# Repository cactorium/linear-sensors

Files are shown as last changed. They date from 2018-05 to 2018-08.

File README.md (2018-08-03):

# Linear PCB sensors
This will eventually contain the sensing mechanisms for several different types of digital calipers.
Luckily the patents on all of them have run out, so I can copy a lot of the exact details used in existing calipers, which should mean there's a lot of a better chance of getting good results out of this.
The designs will be made in KiCAD, and will be under a sufficiently liberal license for you guys to use for whatever.
Hopefully these will be cheap and easy enough to use for a lot of interesting applications, like close looping the axes on 3D printers for a lot cheaper than the $1k+ optical scales that's used on higher end models right now.

**NOTE: the schematic and PCB are now in KiCAD 5. I don't know how backwards compatible it is with older version of KiCAD**

## Capacitance-based sensor v1
~The capactive sensor appears to be working right now, with a sample rate of 96 samples/sec and a precision of about ~ +-0.06 mm (~ +-0.002in), limited by noise.
The accuracy appears to stay within +- 0.01mm for a lot of the range, but the inaccuracy increases at various points (and also if you're touching the scale) along its range.
It's currently affected moderately strongly by mains noise, the next revision will add better filtering to the front end to reduce this issue.~
So the signal is actually incredibly accurate, as long as the surfaces are closely mating and the amplifier isn't clipping.
I'm getting about ~0.002 mm precision (still need to check accuracy across the full range) after carefully adjusting gain to remove clipping.
The signal doesn't appear anything near a sine wave at the output, it mainly consists of a lot of sharp spikes that I guess the FIRs turn into something closer to a sine wave.
It's currently probably limited by the numerical accuracy of the arctangent operation in the processing, but I need to do more testing to see how accurate it is across its range before tuning its precision any more.

There also appear to be some large inaccuracies across its full range, which also I'm currently working out.

## Capacitance-based sensor v2
I reduced the width of the scale by half to try to improve the form factor and added a second stage of filtering to try to reduce its susceptibility to noise.
I removed the large metallic layer that used to overlap the receiving pad to see if that would reduce the amount of noise.
I'm pretty sure covering it with ground will reduce the output signal by adding a lot of parasitic capacitance, so right now it's bare aside from a trace to get the signal from the receiving pad.
There's now three stages of amplification, the first one, which is adjustable and has a gain from 1x to 10x, and two fixed stages which are 2x and ~10x respectively.
There's several stages of low pass and high pass filtering throughout all this, plus some bypass resistors in case this all turns out wrong so I can revert to the v1 analog circuitry in the worst case.
The edges of the PCB were also rounded just to make it look a little nicer, and the mounting holes are now evenly spaced to make mechanical stuff a lot easier to work out.

The BOM cost is about $16, which is pretty reasonable, but I'll probably try to get it a little lower next revision.

The extra filter does appear to work very nicely; the output actually looks like a sine wave, so it might be possible to remove some of the digital filtering while maintaining the same accuracy, but I'm going to work on mechanically stabilizing the setup to get more repeatable measurements.
It does appear to be noticeably better just from rough observations; it takes a lot less effort to get the measurement to where it's bouncing around +- 0.001mm compared with the first revision.
I'm guessing the next revision will focus on improving the form factor and cost.

TODO: add pictures

## How they work
Right now I'm looking at two major designs, inductively coupled ones, developed by Mitutoyo, and the T-shaped capacitively coupled ones used in most cheap caliper designs by Mauser-Werke Oberndorf GmbH.
In both cases, the basic gist is that there's a pattern on the stationary bit (called the stator) that affects its coupling with the bit that moves (let's call it the rotor), and in both cases a phase measurement based on measurements as a result of this coupling is used to get a fine measurement, while a counter is used to keep track of how many times the phase has gone about 360 degrees, giving a coarse measurement.
The actual measurement is simply the sum of these two measurements.

In the Mitutoyo design, a pulse is sent into a transmitting coil, which causes it to resonate.
The EM waves produced by this coil are coupled into a pair of receiving coils.
The receiving coils are shaped so that normally the EM waves perfectly cancel out, but the presence and displacement of the disruptors in the stator cause the cancellation to be incomplete.
The receiving coils are shaped so that they form a sine and cosine wave with respect to the displacement relative to the stator.
The receiving coils resonate in series with a capacitor, and a switch is used to stop the resonation near when the voltage across the capacitor is at its peak.
Then the voltage across the capacitors are read using an ADC, and that's used to calculate the displacement within a single stator period.
A counter's used to get the coarser measurement when the stator's moved greater than one period.

In the Mauser-Werke Oberndorf design, there's many transmitting electrodes, each at a different phase.
Each one is shifted by the same amount relative to the one before it.
In the original design, they formed a set of three before it repeated, with relative phases of 0, 120, 240 degrees.
Modern designs tend to use a set of 8, so that's what we'll use here.
These transmitting electrodes couple with the middle of the tee in the stator design, so that the signal read off the T electrode is effectively the capcitively weighted sum of the electrodes that are coupled (physically over) it.
Shifting the rotor causes the ratios to change, allowing an (very good) approximately linear change in phase for a given displacement.
The wider sections of the T are capactively coupled with a receiving electrode on the rotor, and this is filtered and fed into a zero crossing detector to determine the phase different compared with the input signal, giving you a fine measurement of displacement.
The coarse measurement is found by counting, as in the Mitutoyo case.

TODO add patents to repository

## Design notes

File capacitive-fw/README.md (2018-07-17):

# Firmware for the capacitive sensor board
This is probably not the cleanest directory structure ever, but it works.
The firmware developed here is meant to be programmed onto the STM32F07 chip on the capacitive board.
This provides UART output on the J102 header at 115200 baud (adjustable in the source code) of the current position, output as a 64 bit hexadecimal, followed by a space and 64 zeros (TODO remove extra output).
The button on the board zeros out the reading, and the reading can also be zeroed out by sending a "z" into the UART port.

The project is currently using `libopencm3` to avoid needing to read through the STM32F07 reference manual, and the OpenOCD config is for the FT232H chip. TODO provide more info about SWD programming with Adafruit's FT232H breakout
Any SWD-capable OpenOCD-compatible programmer should work.
You'll need the `arm-none-eabi-gcc` toolchain to build the project, although I'll probably add the final binaries to this repository at some point.

## How it works (TLDR)
Basically the position is approximately linear with respect to the detected phase of the signal, so the MCU needs to clean up the signal and find its phase to find its position.

## Internals
Most of the processing is done in the main loop, with interrupts providing the timing for the ADC conversion and square waves.
The system tick interrupt provides the timing for the entire system; it starts ADC conversions and toggles GPIO for the square waves.
The ADC interrupts stores the samples into a buffer, where it'll be slowly processed by the main loop.
Due to the limitations in processing speed, the ADC doesn't run continuously.
Instead, the ADC runs for the first N cycles of the square waves, enough to fill the buffer, with the ADC turned off for the remaining portion of the time. (maybe this is leading to more noise? TODO experiment with changing timing)
The number of ADC cycles and total cycles are easily adjusted to allow experimentation to try to improve latency or improve performance.
There's an overrun detector that'll output an 'o' onto the UART line whenever the main loop is taking too long to process the data.

The main loop passes the ADC samples into a cascade of three FIR filters, to reduce a lot of the mains noise and harmonics in the signal.
This is then multiplied with a 1 kHz cosine and 1 kHz sine wave to produce I (in phase) and Q (quadrature) components, which are summed over the entire sampling period.
This is then fed into an arctangent function based on CORDIC (Volder's algorithm) to produce this final phase information.

A lot of the experimenting done to design these filters and test out CORDIC is available under the `filter/` directory.

All of the math is done in a mixture of 32-bit and 64-bit math, with care to avoid any unnecessary multiplication and to avoid doing any divisions with anything other than a power of 2.
This proved vital in reaching the desired performance of the unit.

### Development notes
All the Python files in `src/` are used to generate constants and headers and stuff.
TODO add these to the Makefile

## How to build

```
cd src/
make
make flash
```

## TODOs
- [ ] Wire up the voltage protection MOSFET correctly
- [ ] Switch out JTAG header with SMD one
- [ ] Add front end filter components
- [ ] Maybe swap to a higher performance MCU
- [ ] Order and test on a longer scale board
- [ ] Test and verify that the board is actually outputting accurate data

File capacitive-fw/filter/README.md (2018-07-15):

Testing out the FIR filters to use on the STM32; there's a lot of 60 Hz noise and harmonics in the signal, so we need to filter them out before using the periodogram to calculate phase.

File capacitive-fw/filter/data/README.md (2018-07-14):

Data was collected using commit `cbe28079ba94519dbe33b98c67d5848d1041f939` version of the code.
In this version of the code, sending a 'd' across the USART causes the program to dump its 1000 samples of ADC data in hex.

So I ran this in one terminal:
```
cat /dev/ttyUSB0 > data0
```
and opened up picocom in another and pressed 'd'

There's probably a better way to do it but this works well enough

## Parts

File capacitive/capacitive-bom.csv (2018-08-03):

Reference | Quantity | Identifier | Package | Value | Tolerance | Voltage | Current | Power | PN | Mouser
U101 | 1 |  |  | STM32F070C6T6 |  |  |  |  |  | 511-STM32F070C6T6
C111;C103;C110;C101;C104;C105;C102;C118;C121;C112;C113;C107 | 12 |  |  | 100nF 20% |  |  |  |  |  | 710-885012207016
R103;R119 | 2 |  |  | 1.58k 1% |  |  |  |  |  | 660-RN73H1JTD1581D25
C108;C125 | 2 |  |  | 100nF 2% |  |  |  |  |  | 667-ECH-U1C104GX5
C109 | 1 |  |  | 10 nF 1% |  |  |  |  |  | 81-GRM2195C1H103FA1D
R105;R126;R102 | 3 |  |  | 1k 1% |  |  |  |  |  | 71-CRCW04021K00FKEDC
R108;R115;R124 | 3 |  |  | DNP |  |  |  |  |  | 71-RCS06030000Z0EA
J102 | 1 |  |  | UART |  |  |  |  |  | 855-M20-9990445
J103 | 1 |  |  | SWD |  |  |  |  |  | 855-M20-8750342
C106 | 1 |  |  | 10nF 10% |  |  |  |  |  | 80-C0603C103M5RAUTO
R101 | 1 |  |  | 100 |  |  |  |  |  | 71-CRCW0603100RFKEAC
RV101 | 1 |  |  | 100k linear |  |  |  |  |  | 72-T70YE-100K
R106;R109;R110;R112;R107;R127;R117;R121;R123;R122 | 10 |  |  | 100k 1% |  |  |  |  |  | 71-CRCW1206100KFKEAC
C120;C116;C117;C119;C115;C114;C123 | 7 |  |  | 10uF 10% |  |  |  |  |  | 581-TAJB106K020RNJV
J106 | 1 |  |  | POWER |  |  |  |  |  | NoPart
TP108;TP107;TP106;TP105;TP104;TP103;TP101;TP109;TP102;TP111;TP112;TP110 | 12 |  |  | TEST |  |  |  |  |  | NoPart
U103 | 1 |  |  | SG7050CAN_8.000000M-TJGA3 |  |  |  |  |  | 732-7050CA8.00TJGA3
U104 | 1 |  |  | TLV74133PDBVR |  |  |  |  |  | 595-TLV74133PDBVR
J104 | 1 |  |  | TX_PADS |  |  |  |  |  | NoPart
J105 | 1 |  |  | RX_PAD |  |  |  |  |  | NoPart
SW101 | 1 |  |  | SW_Push |  |  |  |  |  | 612-LL3301NF065QG
R111 | 1 |  |  | 1 5% |  |  |  |  |  | 755-ESR03EZPJ1R0
Q101 | 1 |  |  | RU1C002ZPTCL |  |  |  |  |  | 755-RU1C001ZPTL
D102 | 1 |  |  | ESD9X5.0ST5G |  |  |  |  |  | 863-ESD9X5.0ST5G
RV102 | 1 |  |  | 5k linear |  |  |  |  |  | 81-PVG5H502C03B00
J108 | 1 |  |  | LL |  |  |  |  |  | NoPart
J109 | 1 |  |  | LR |  |  |  |  |  | NoPart
J107 | 1 |  |  | UR |  |  |  |  |  | NoPart
J101 | 1 |  |  | UL |  |  |  |  |  | NoPart
D101;D103 | 2 |  |  | ESD9B3.3ST5G |  |  |  |  |  | 863-ESD9B3.3ST5G
R113;R114;R125;R120 | 4 |  |  | 0 |  |  |  |  |  | 71-CRCW12060000Z0EAC
R104 | 1 |  |  | 15.8k 1% |  |  |  |  |  | 667-ERJ-8ENF1582V
U102 | 1 |  |  | TLV9064IPWR |  |  |  |  |  | 595-TLV9064IPWR
R118 | 1 |  |  | 10k 1% |  |  |  |  |  | 71-CRCW040210K0FKEDC
C124 | 1 |  |  | 1.8nF 2% |  |  |  |  |  | 81-GRM1885C1H182GA1D
C126;C127 | 2 |  |  | 33nF 5% |  |  |  |  |  | 80-C0603C333J4RECLR

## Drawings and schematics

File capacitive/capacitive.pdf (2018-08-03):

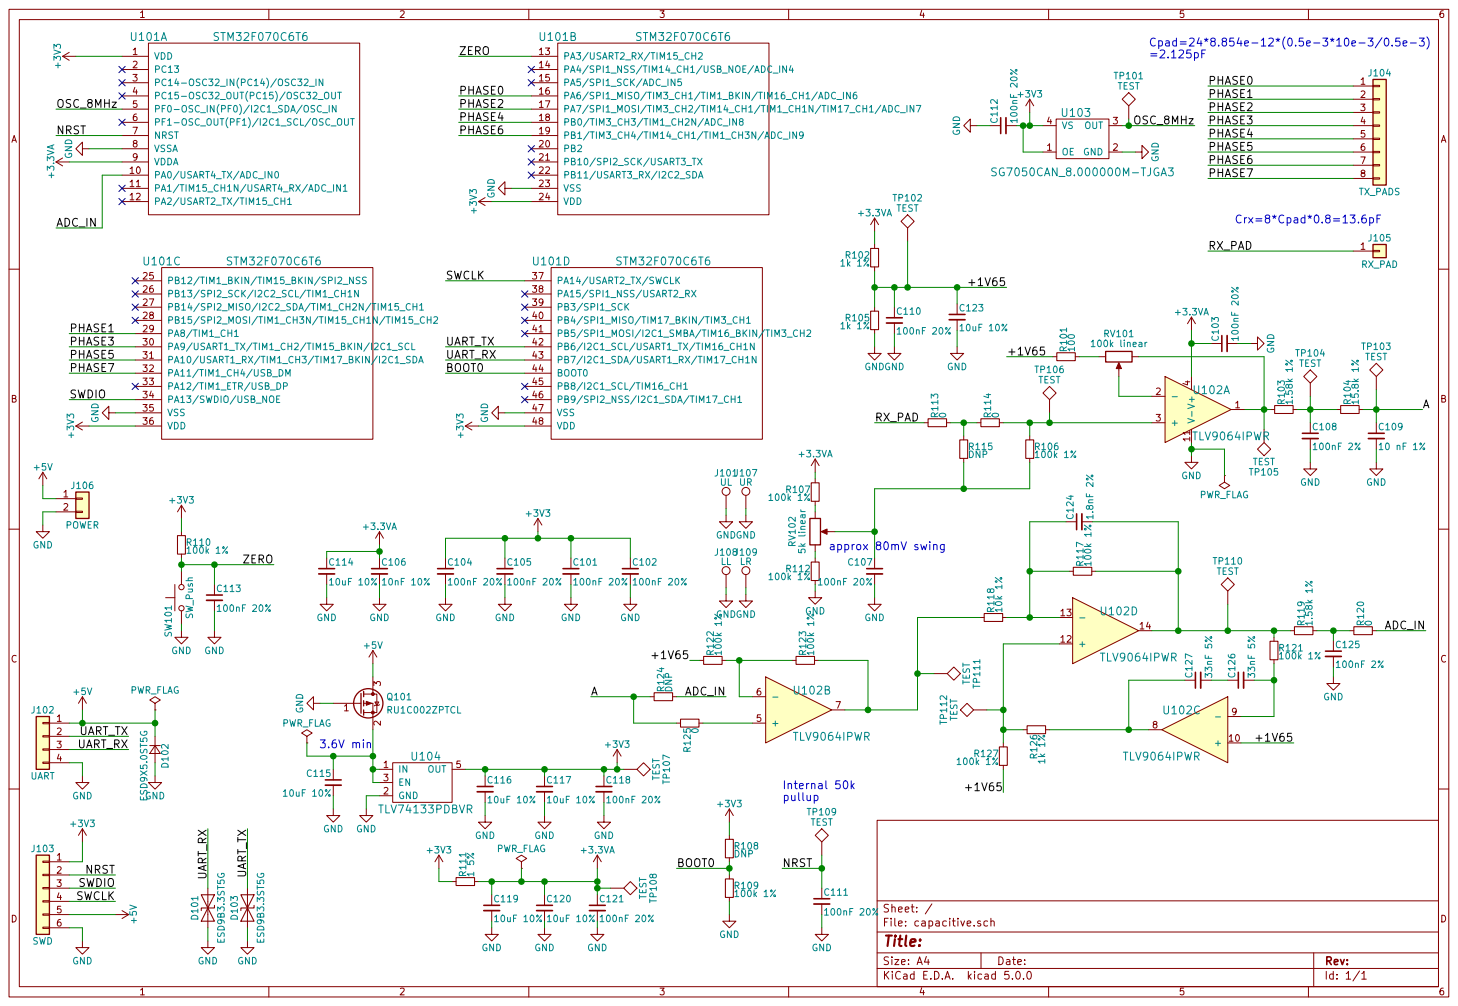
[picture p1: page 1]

File: capacitive.sch Sheet: /
Id: 1/1 Title:

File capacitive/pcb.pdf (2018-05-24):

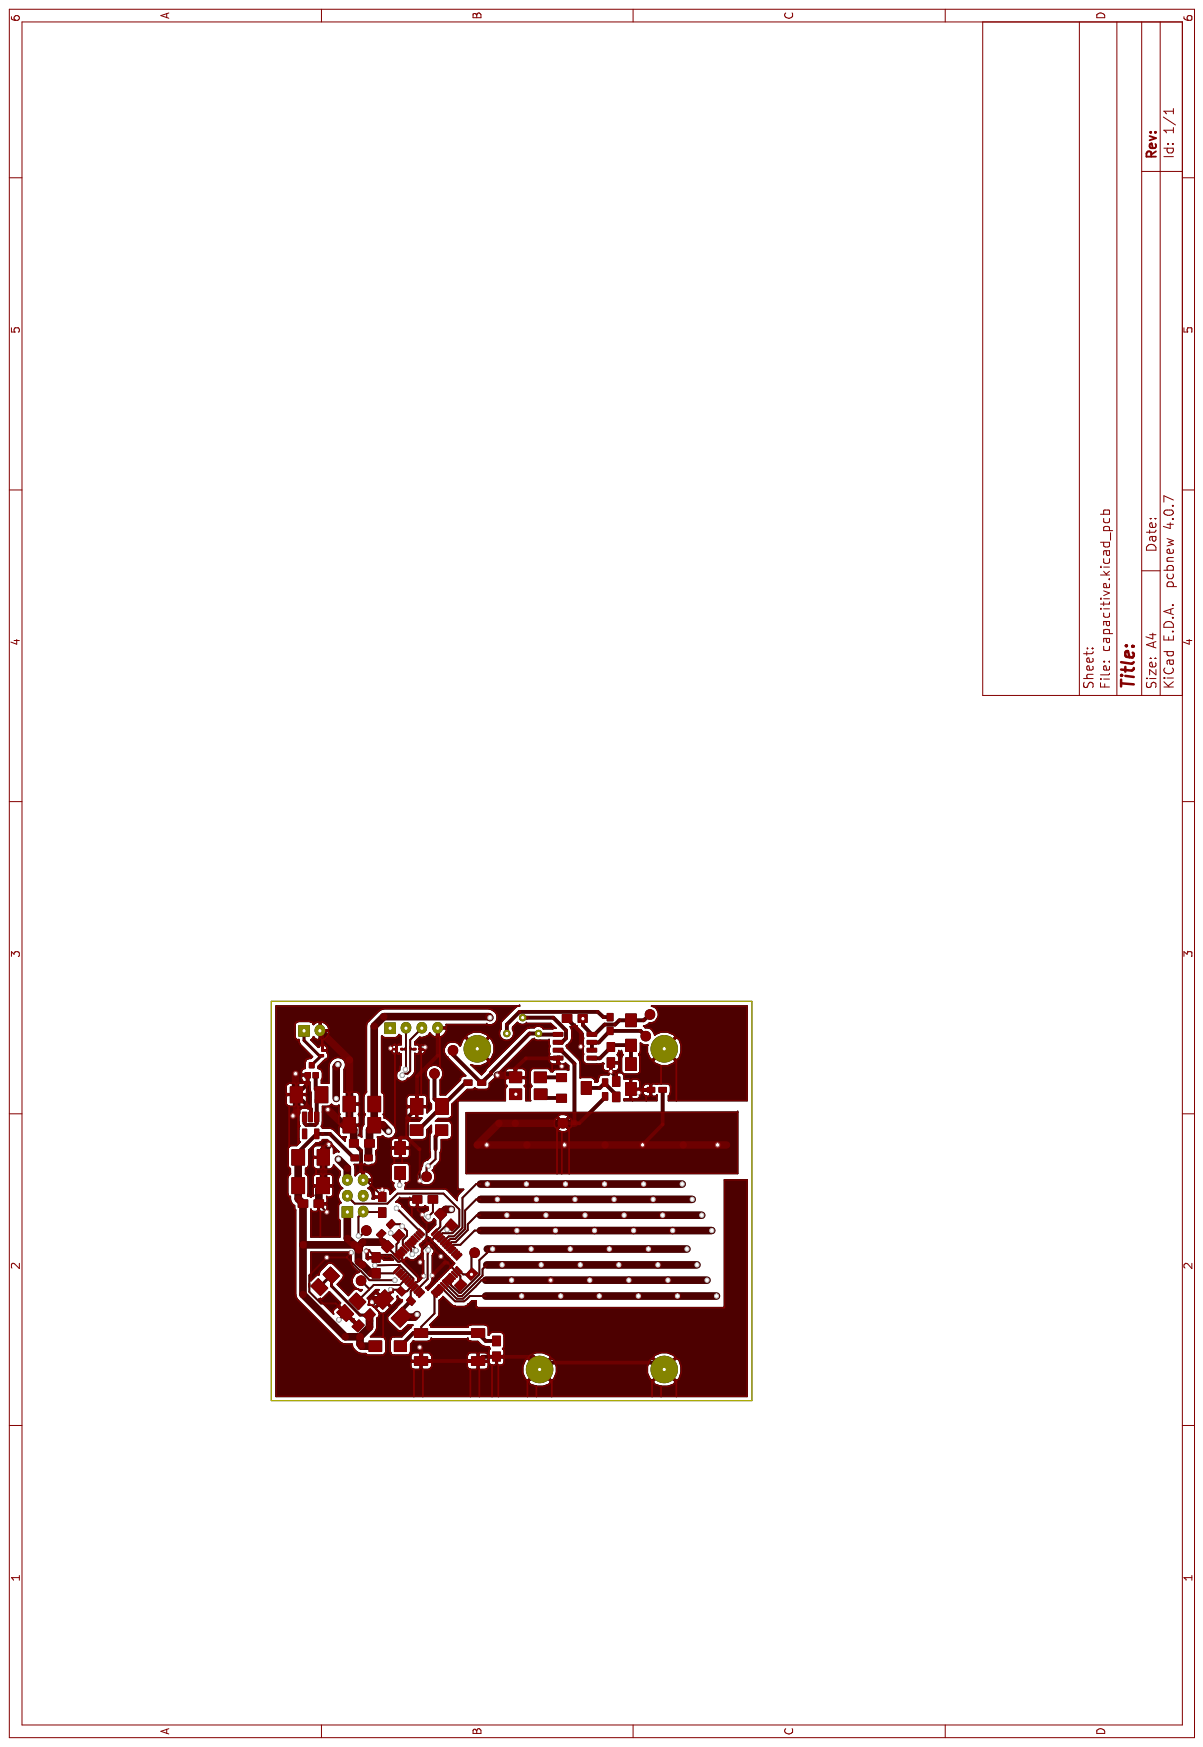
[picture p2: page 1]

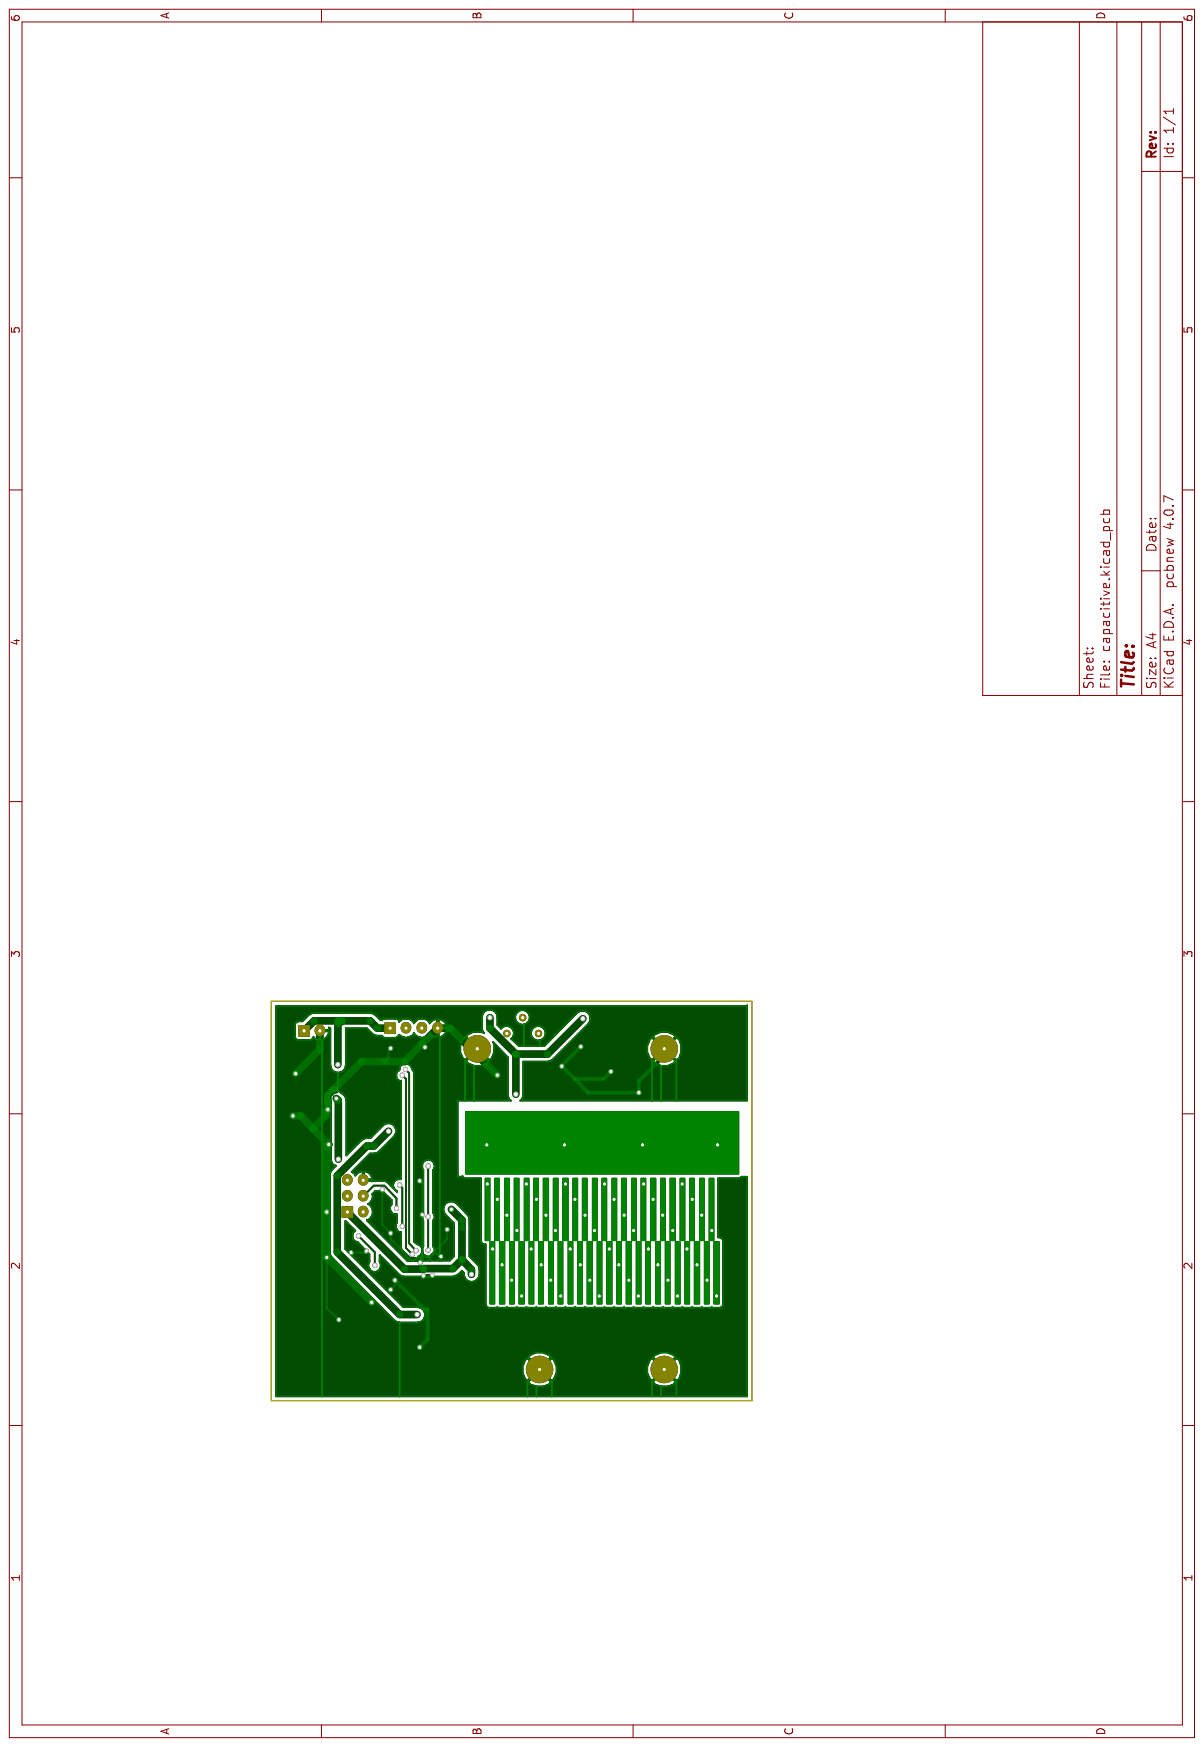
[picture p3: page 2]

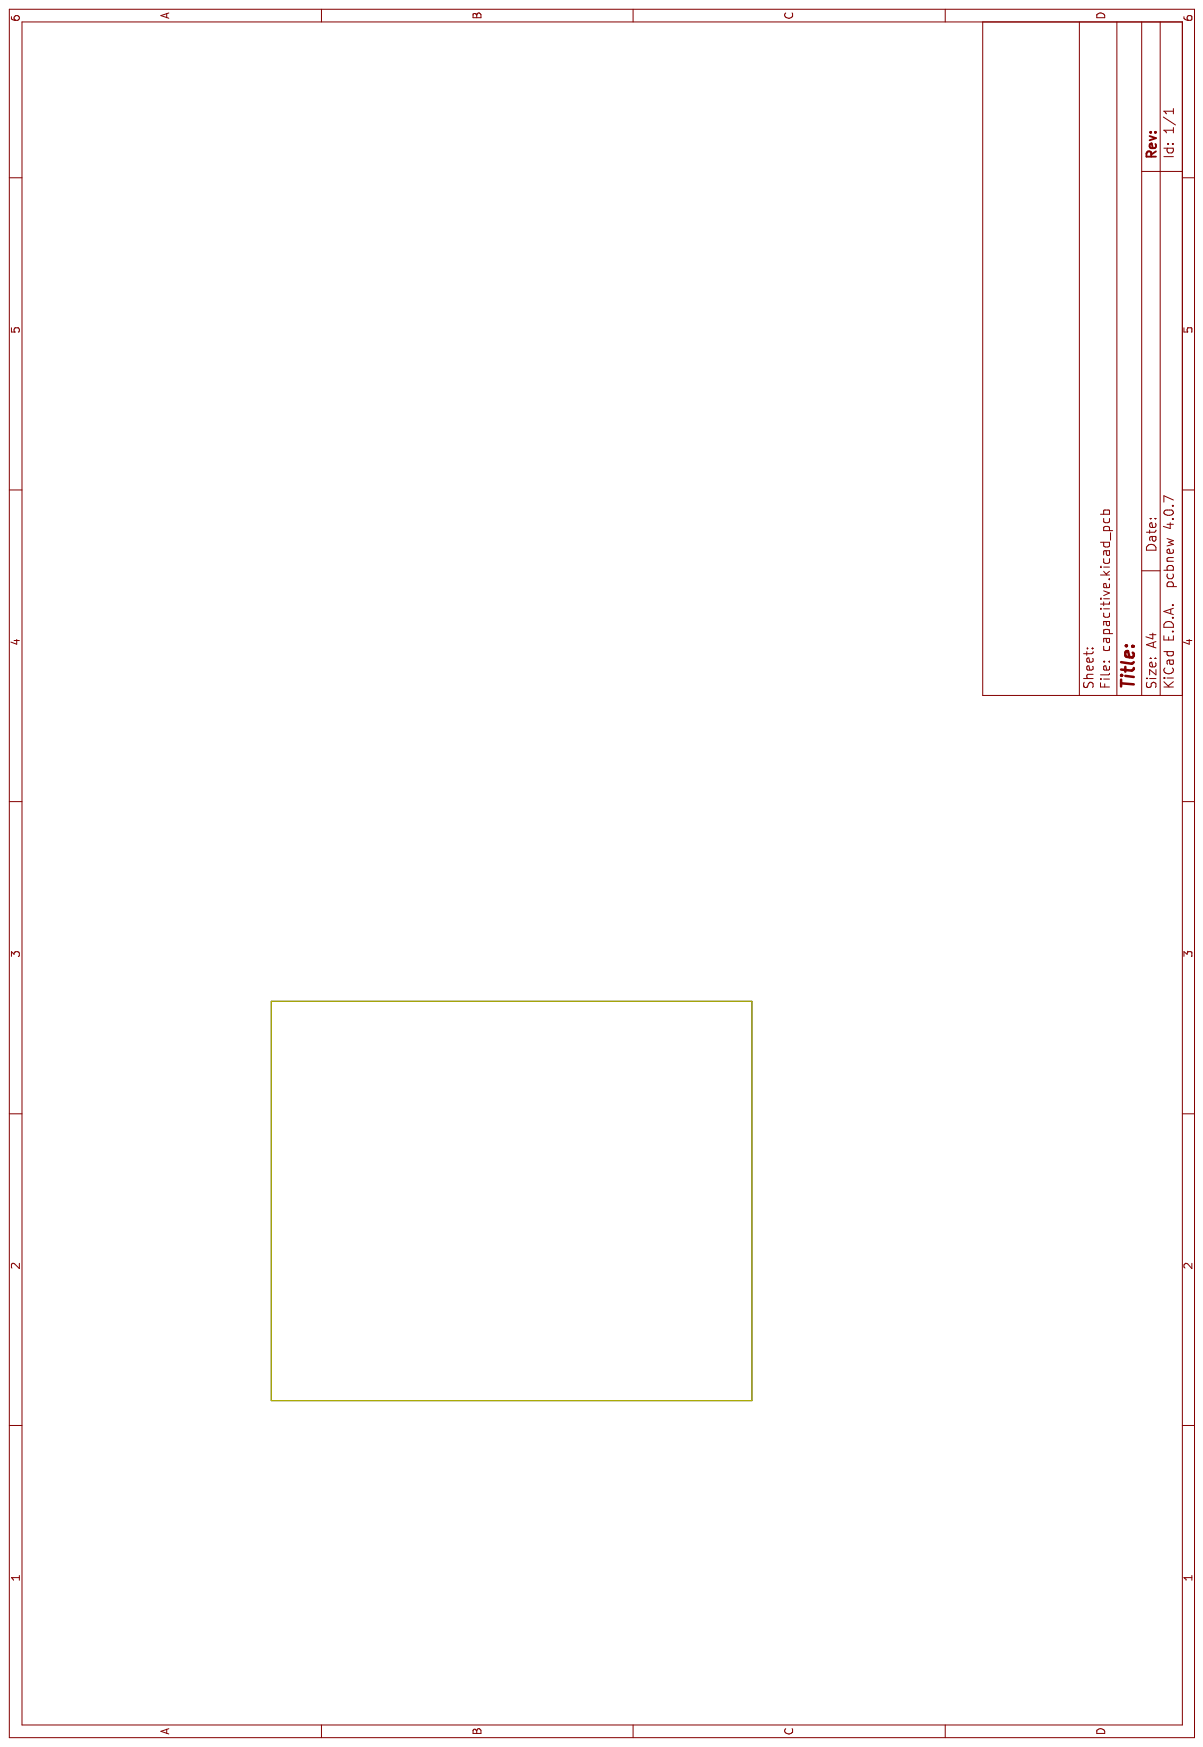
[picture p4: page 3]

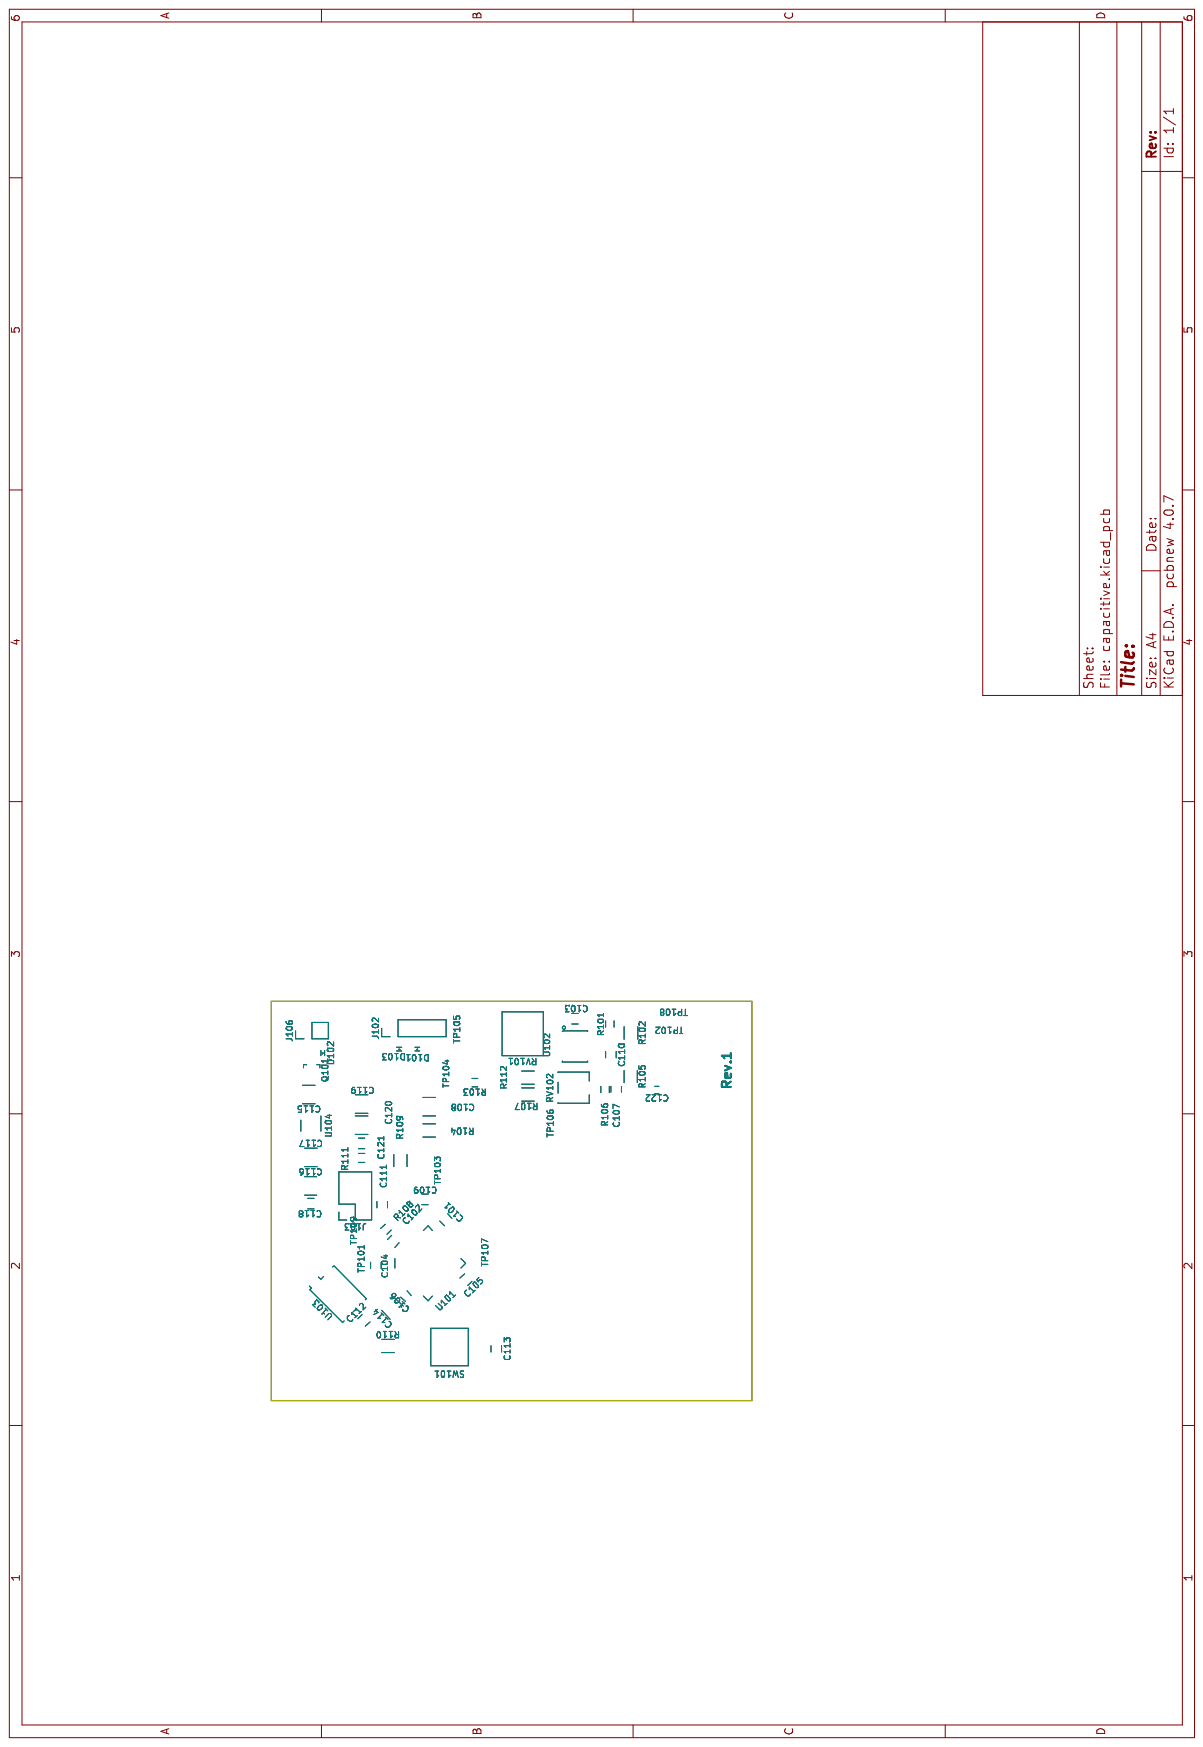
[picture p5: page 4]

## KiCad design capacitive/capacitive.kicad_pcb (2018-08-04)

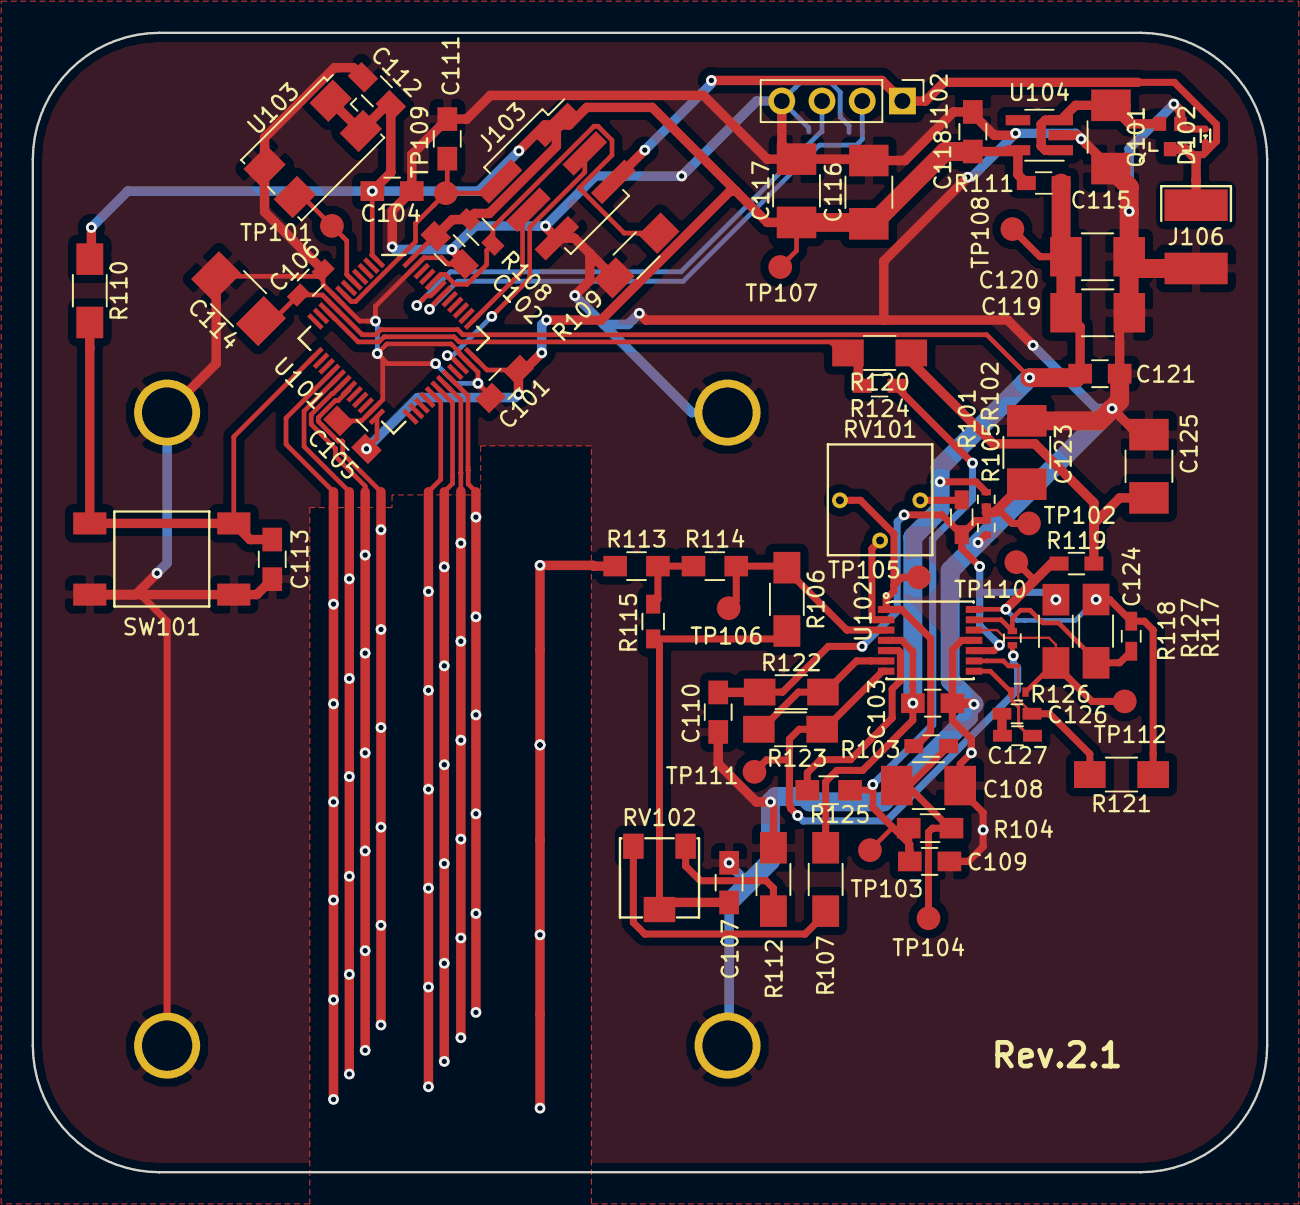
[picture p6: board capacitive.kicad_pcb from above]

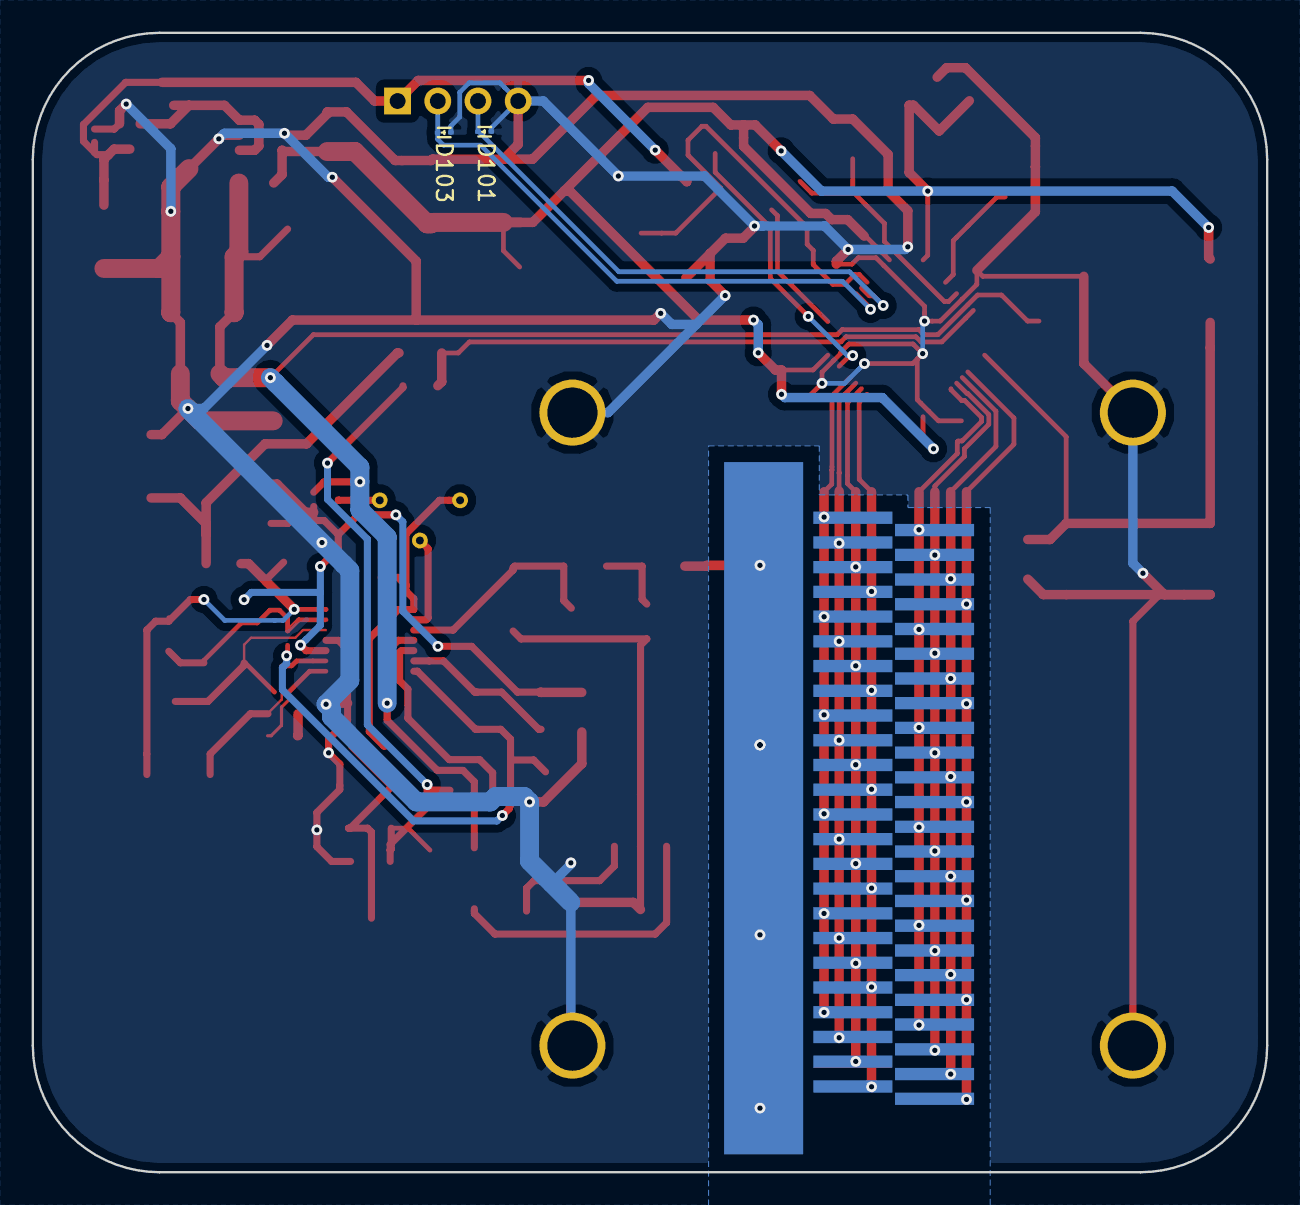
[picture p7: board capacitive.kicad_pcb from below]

Board: 2 copper layers, 78.0 x 72.0 mm, 84 parts (4 on the bottom side), 44 nets.

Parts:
C101, C102, C103, C104, C105, C107, C110, C111, C112, C113, C118, C121: 100nF 20%; C_0805_HandSoldering
C106: 10nF 10%; R_0603_HandSoldering
C108, C125: 100nF 2%; C_1210_HandSoldering
C109: 10 nF 1%; C_0805_HandSoldering
C114, C115, C116, C117, C119, C120, C123: 10uF 10%; C_1210_HandSoldering
C124: 1.8nF 2%; C_0603_HandSoldering
C126, C127: 33nF 5%; C_0603_HandSoldering
D101, D103: ESD9B3.3ST5G; SOD-923
D102: ESD9X5.0ST5G; SOD-923
J101: UL; Slide_Drill_Left
J102: UART; Socket_Strip_Straight_1x04_Pitch2.54mm
J103: SWD; Socket_Strip_Straight_2x03_Pitch2.54mm_SMD
J104: TX_PADS
J105: RX_PAD
J106: POWER; Power_Pads
J107: UR; Slide_Drill_Right
J108: LL; Slide_Drill_Left
J109: LR; Slide_Drill_Right
Q101: RU1C002ZPTCL; Rohm_UMT3F
R101: 100; R_0603_HandSoldering
R102, R105, R126: 1k 1%; R_0402
R103, R119: 1.58k 1%; R_0603_HandSoldering
R104: 15.8k 1%; R_0805_HandSoldering
R106, R107, R109, R110, R112, R117, R121, R122, R123, R127: 100k 1%; R_1206_HandSoldering
R108, R115, R124: DNP; R_0603_HandSoldering
R111: 1 5%; R_0603_HandSoldering
R113, R114, R125: 0; R_0805_HandSoldering
R118: 10k 1%; R_0402
R120: 0; R_1206_HandSoldering
RV101: 100k linear; Vishay_T73YE
RV102: 5k linear; Bourns-PVG5H
SW101: SW_Push; LL3301NF065QG
TP101, TP102, TP103, TP104, TP105, TP106, TP107, TP108, TP109, TP110, TP111, TP112: TEST; Measurement_Point_Round-SMD-Pad_Small
U101: STM32F070C6T6; ST_LQFP48
U102: TLV9064IPWR; TI_TSSOP14
U103: SG7050CAN_8.000000M-TJGA3; Crystal_SMD_7050-4pin_7.0x5.0mm
U104: TLV74133PDBVR; SOT-23-5_HandSoldering

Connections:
+3.3VA: C103.1, C106.1, C114.1, C119.1, C120.1, C121.1, R102.1, R107.1, R111.2, TP108.1, U101.9, U102.4
+3V3: C101.1, C102.1, C104.1, C105.1, C112.2, C116.1, C117.1, C118.1, J103.1, R108.1, R110.1, R111.1, TP107.1, U101.1, U101.24, U101.36, U101.48, U103.1, U103.4, U104.5
+5V: D102.1, J102.1, J103.5, J106.1, Q101.3
/+1V65: C110.1, C123.1, R101.1, R102.2, R105.1, R122.1, R127.2, TP102.1, U102.10
/A: C109.1, R104.2, R124.1, R125.1, TP103.1
/ADC_IN: R120.2, R124.2, U101.10
/BOOT0: R108.2, R109.1, U101.44
/NRST: C111.1, J103.2, TP109.1, U101.7
/OSC_8MHz: TP101.1, U101.5, U103.3
/PHASE0: J104.1, U101.16
/PHASE1: J104.2, U101.29
/PHASE2: J104.3, U101.17
/PHASE3: J104.4, U101.30
/PHASE4: J104.5, U101.18
/PHASE5: J104.6, U101.31
/PHASE6: J104.7, U101.19
/PHASE7: J104.8, U101.32
/RX_PAD: J105.1, R113.1
/SWCLK: J103.4, U101.37
/SWDIO: J103.3, U101.34
/UART_RX: D101.1, J102.3, U101.43
/UART_TX: D103.1, J102.2, U101.42
/ZERO: C113.1, R110.2, SW101.1, U101.13
GND: C101.2, C102.2, C103.2, C104.2, C105.2, C106.2, C107.2, C108.2, C109.2, C110.2, C111.2, C112.1, C113.2, C114.2, C115.2, C116.2, C117.2, C118.2, C119.2, C120.2, C121.2, C123.2, C125.2, D101.2, D102.2, D103.2, J101.1, J102.4, J103.6, J106.2, J107.1, J108.1, J109.1, Q101.1, R105.2, R109.2, R112.2, SW101.2, U101.8, U101.23, U101.35, U101.47, U102.11, U103.2, U104.2
unnamed: C107.1, R106.2, R115.2, RV102.2
unnamed: C108.1, R103.2, R104.1, TP104.1
unnamed: C115.1, Q101.2, U104.1, U104.3
unnamed: C124.1, R117.1, R118.2, U102.13
unnamed: C124.2, R117.2, R119.1, R121.1, TP110.1, U102.14
unnamed: C125.1, R119.2, R120.1
unnamed: C126.1, C127.2
unnamed: C126.2, R121.2, U102.9
unnamed: C127.1, R126.2, U102.8
unnamed: R101.2, RV101.3
unnamed: R103.1, RV101.1, TP105.1, U102.1
unnamed: R106.1, R114.2, TP106.1, U102.3
unnamed: R107.2, RV102.1
unnamed: R112.1, RV102.3
unnamed: R113.2, R114.1, R115.1
unnamed: R118.1, R123.2, TP111.1, U102.7
unnamed: R122.2, R123.1, U102.6
unnamed: R125.2, U102.5
unnamed: R126.1, R127.1, TP112.1, U102.12
unnamed: RV101.2, U102.2

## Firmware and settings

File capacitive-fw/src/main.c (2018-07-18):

#include <stdint.h>

#include <libopencm3/stm32/rcc.h>
#include <libopencm3/stm32/adc.h>
#include <libopencm3/stm32/gpio.h>
#include <libopencm3/stm32/usart.h>

#include <libopencm3/cm3/nvic.h>
#include <libopencm3/cm3/systick.h>

#define FIR_HP_BUFFER_SZ (100)
#define FIR_LP_BUFFER_SZ1 (64)
#define FIR_LP_BUFFER_SZ2 (32)

static int32_t feed_fir1(uint16_t i);
static int32_t feed_fir2(int32_t i);
static int32_t feed_fir3(int32_t i);

#include "trig.h"

#define FULL_SCALE          6.25
#define HALF_SCALE          (6.25/2)

#define FULL_SCALE_PHASE_UNITS  ((int64_t)(FULL_SCALE*(1 << 31)))
#define HALF_SCALE_PHASE_UNITS  ((int64_t)(HALF_SCALE*(1 << 31)))

#define BASE_FREQ           1000
#define SAMPLE_RATE         96000
#define SAMPLE_NUM_PERIODS  8
#define TOTAL_NUM_PERIODS   10
#define BASE_PERIOD         (SAMPLE_RATE/BASE_FREQ)
#define SAMPLE_BUFFER_SZ    (SAMPLE_NUM_PERIODS*BASE_PERIOD)
#define SAMPLE_PERIOD       SAMPLE_BUFFER_SZ 

#define PHASE_PIN(x) ((uint32_t[]){GPIO6, GPIO8, GPIO7, GPIO9, GPIO0, GPIO10, GPIO1, GPIO11})[x]
#define IS_PORT_B(x) ((uint8_t[]){0, 0, 0, 0, 1, 0, 1, 0})[x]
#define PHASE_PORT(x) (IS_PORT_B(x) ? GPIO_PORT_B_BASE : GPIO_PORT_A_BASE)

#define PINA_MASK(x) (IS_PORT_B(x) ? 0 : PHASE_PIN(x))
#define PINB_MASK(x) (IS_PORT_B(x) ? PHASE_PIN(x) : 0)

#define TX_PIN GPIO6 // port B
#define RX_PIN GPIO7 // port B
#define ZERO_PIN GPIO3 // port A
#define ADC_PIN GPIO0 // port A

static void clock_setup() {
  // use external clock
  rcc_clock_setup_in_hse_8mhz_out_48mhz();
}

static void gpio_setup() {
	// enable clocks for GPIO
	rcc_periph_clock_enable(RCC_GPIOA);
	rcc_periph_clock_enable(RCC_GPIOB);

  // set up pins for pulses
  gpio_mode_setup(GPIO_PORT_A_BASE, GPIO_MODE_OUTPUT, GPIO_PUPD_NONE,
      PINA_MASK(0)|PINA_MASK(1)|PINA_MASK(2)|PINA_MASK(3)|
      PINA_MASK(4)|PINA_MASK(5)|PINA_MASK(6)|PINA_MASK(7));
  gpio_mode_setup(GPIO_PORT_B_BASE, GPIO_MODE_OUTPUT, GPIO_PUPD_NONE,
      PINB_MASK(0)|PINB_MASK(1)|PINB_MASK(2)|PINB_MASK(3)|
      PINB_MASK(4)|PINB_MASK(5)|PINB_MASK(6)|PINB_MASK(7));

  gpio_clear(GPIO_PORT_A_BASE, PINA_MASK(0)|PINA_MASK(1)|PINA_MASK(2)|PINA_MASK(3));
  gpio_clear(GPIO_PORT_B_BASE, PINB_MASK(0)|PINB_MASK(1)|PINB_MASK(2)|PINB_MASK(3));

  gpio_set(GPIO_PORT_A_BASE, PINA_MASK(4)|PINA_MASK(5)|PINA_MASK(6)|PINA_MASK(7));
  gpio_set(GPIO_PORT_B_BASE, PINB_MASK(4)|PINB_MASK(5)|PINB_MASK(6)|PINB_MASK(7));

  // set up pins for usart
  gpio_mode_setup(GPIO_PORT_B_BASE, GPIO_MODE_AF, GPIO_PUPD_NONE, TX_PIN|RX_PIN);
  gpio_set_af(GPIO_PORT_B_BASE, GPIO_AF0, TX_PIN|RX_PIN);

  // set up pin for ADC
  gpio_mode_setup(GPIO_PORT_A_BASE, GPIO_MODE_ANALOG, GPIO_PUPD_NONE, ADC_PIN);
}

static void systick_setup() {
  // disable counter and interrupt
  systick_interrupt_disable();
  systick_counter_disable();

  systick_set_clocksource(STK_CSR_CLKSOURCE);
  // 96 kHz system clock
  systick_set_reload(48000000/96000-1);
  systick_clear();

  systick_interrupt_enable();
  systick_counter_enable();
}

static void adc_setup() {
  // enable clock for ADC
  rcc_periph_clock_enable(RCC_ADC);

  adc_power_off(ADC1);
  // divide 48 MHz by 4 to get 12 MHz; max clock is 14 MHz
  adc_set_clk_source(ADC1, ADC_CLKSOURCE_PCLK_DIV4);
  adc_calibrate(ADC1);
  adc_set_single_conversion_mode(ADC1);
  adc_set_right_aligned(ADC1);

  static uint8_t channels[] = { 0 };
  adc_set_regular_sequence(ADC1, 1, channels);

  adc_set_sample_time_on_all_channels(ADC1, ADC_SMPTIME_007DOT5);
	adc_set_resolution(ADC1, ADC_RESOLUTION_12BIT);

  adc_disable_external_trigger_regular(ADC1);
	adc_disable_analog_watchdog(ADC1);

  nvic_enable_irq(NVIC_ADC_COMP_IRQ);
  adc_enable_eoc_interrupt(ADC1);

	adc_power_on(ADC1);
}

static void uart_setup() {
	// enable clocks for USART1
	rcc_periph_clock_enable(RCC_USART1);

	usart_set_baudrate(USART1, 115200);
	usart_set_databits(USART1, 8);
	usart_set_parity(USART1, USART_PARITY_NONE);
	usart_set_stopbits(USART1, USART_CR2_STOPBITS_1);
	usart_set_mode(USART1, USART_MODE_TX_RX);
	usart_set_flow_control(USART1, USART_FLOWCONTROL_NONE);

  nvic_enable_irq(NVIC_USART1_IRQ);
  usart_enable_rx_interrupt(USART1);

	usart_enable(USART1);
}


volatile int32_t adc_idx = -1;
volatile int32_t sample_idx = -1;
volatile uint8_t calc_finished = 0;
volatile uint8_t sample_full = 0;

// sys tick rate is 96 KHz
void sys_tick_handler() {
  static uint8_t tick = 0;
  // start a conversion
  if (adc_idx < SAMPLE_BUFFER_SZ) {
    adc_start_conversion_regular(ADC1);
  }

  if (tick == 0 && adc_idx >= TOTAL_NUM_PERIODS*BASE_PERIOD) {
    if (calc_finished) {
      sample_idx = -1;
      adc_idx = 0;
      calc_finished = 0;
      sample_full = 0;
    } else {
      usart_send(USART1, 'o');
    }
  } else {
    ++adc_idx;
  }
  // 96 KHz/12 = 8 KHz
  int tick_half = tick;
  if (tick_half >= 48) {
    tick_half -= 48;
  }
  if (tick_half == 0) { 
    gpio_toggle(PHASE_PORT(0), PHASE_PIN(0));
    gpio_toggle(PHASE_PORT(4), PHASE_PIN(4));
  } else if (tick_half == 12) {
    gpio_toggle(PHASE_PORT(1), PHASE_PIN(1));
    gpio_toggle(PHASE_PORT(5), PHASE_PIN(5));
  } else if (tick_half == 24) {
    gpio_toggle(PHASE_PORT(2), PHASE_PIN(2));
    gpio_toggle(PHASE_PORT(6), PHASE_PIN(6));
  } else if (tick_half == 36) {
    gpio_toggle(PHASE_PORT(3), PHASE_PIN(3));
    gpio_toggle(PHASE_PORT(7), PHASE_PIN(7));
  }
  ++tick;
  if (tick == 96) {
    tick = 0;
  }
}

volatile uint16_t samples[SAMPLE_BUFFER_SZ];
volatile uint8_t zero_mode = 0;

void adc_comp_isr() {
  int idx = adc_idx;
  int tmp = adc_read_regular(ADC1);
  samples[idx] = tmp;
  sample_idx = idx;
  if (idx == SAMPLE_BUFFER_SZ - 1) {
    sample_full = 1;
  }
}

enum usart_state {
  USART_FSM_IDLE,
  USART_FSM_SAMPLES,
  USART_FSM_DEBUG,
  USART_FSM_WRITE_IQ_INIT,
  USART_FSM_WRITE_IQ_DOWRITE
} usart_state = USART_FSM_IDLE;

union {
  struct {
    int8_t nibble;
    int16_t word;
  } samples;
  struct {
    int8_t nibble;
    int16_t word;
  } debug;
  struct {
    int8_t nibble;
    int16_t word;
  } iq;
} usart_data;

static void run_tx_fsm();

void usart1_isr() {
  if (usart_get_flag(USART1, USART_ISR_RXNE)) {
    uint16_t c = usart_recv(USART1);
    if (usart_state == USART_FSM_IDLE) {
      if (c == 'i') {
        usart_state = USART_FSM_DEBUG;
        usart_data.debug.nibble = 0;
        usart_data.debug.word = 0;
      }
      if (c == 'd' && sample_full) {
        usart_state = USART_FSM_SAMPLES;
        usart_data.samples.nibble = 0;
        usart_data.samples.word = 0;
      }
      if (c == 'z') {
        zero_mode = 1;
      }
    }
  }
  // clear the TX flag in case we're not transmitting something
  run_tx_fsm();
}

#include "trig.c"

uint8_t phase_started = 0;
int64_t phase_i = 0;
int64_t phase_q = 0;
uint16_t phase_calc_count = 0;

static void feed_phase_start() {
  phase_calc_count = 0;
  phase_started = 1;
  phase_i = 0;
  phase_q = 0;
}

// returns 1 if the period has finished, 0 otherwise
static int8_t feed_phase_calc(int32_t val) {
  // wait until the feed's been started
  if (!phase_started) {
    return 0;
  }
  if (phase_calc_count < SAMPLE_PERIOD) {
    phase_i += (((int64_t)cos32(phase_calc_count))*val)/2048;
    phase_q += (((int64_t)sin32(phase_calc_count))*val)/2048;
  }
  phase_calc_count++;
  return phase_calc_count == SAMPLE_PERIOD;
}

uint8_t iq_ready = 0;
uint64_t usart_i, usart_q;

#include "cordic.c"

int64_t cur_phase = 0;
int64_t phase_offset = 0;
int64_t whole_steps = 0;

static int64_t abs64(int64_t x) {
  return (x > 0) ? x : -x;
}
// have the ADC ISR fill up a buffer with values while
// calculating over it in the main loop. empty the buffer after the calculation
// is complete and wait for the start of the next cycle
int main() {
  clock_setup();

  gpio_setup();
  uart_setup();
  adc_setup();
  systick_setup();

  while (1) {
    feed_phase_start();
    for (int i = 0; i < SAMPLE_BUFFER_SZ; ++i) {
      while (sample_idx < i) {}
      const uint16_t tmp = samples[i];

      const int32_t fir_out1 = feed_fir1(tmp);
      const int32_t fir_out2 = feed_fir2(fir_out1);
      const int32_t fir_out3 = feed_fir3(fir_out2);

      feed_phase_calc(fir_out3);
    }
    const int64_t new_phase = cordic_scaled_atan(phase_i, phase_q);
    const int64_t phase_up = whole_steps + FULL_SCALE_PHASE_UNITS + new_phase;
    const int64_t phase_down = whole_steps - FULL_SCALE_PHASE_UNITS + new_phase;
    const int64_t phase_same = whole_steps + new_phase;

    const int64_t up_diff = abs64(phase_up - cur_phase);
    const int64_t down_diff = abs64(phase_down - cur_phase);
    const int64_t zero_diff = abs64(phase_same - cur_phase);

    if ((up_diff < down_diff) && (up_diff < zero_diff)) {
      cur_phase = phase_up;
      whole_steps += FULL_SCALE_PHASE_UNITS;
    } else if ((down_diff < up_diff) && (down_diff < zero_diff)) {
      cur_phase = phase_down;
      whole_steps -= FULL_SCALE_PHASE_UNITS;
    } else {
      cur_phase = phase_same;
    }

    if (!(gpio_port_read(GPIOA) & ZERO_PIN) || zero_mode) {
      phase_offset = -cur_phase;
      zero_mode = 0;
    }

    calc_finished = 1;
    usart_i = cur_phase + phase_offset;
    usart_q = 0;
    while (usart_state == USART_FSM_IDLE) {
      // NOTE: race condition with a USART receive at the exact same moment
      // so that's why this is reduced to a single instruction, to make
      // failure impotent instead of potentially causing data corruption
      usart_state = USART_FSM_WRITE_IQ_INIT;
      usart_enable_tx_interrupt(USART1);
      nvic_set_pending_irq(NVIC_USART1_IRQ);
    }
    while (calc_finished) {}
  }

  return 0;
}

const char hexstr[] = "0123456789abcdef";
static void usart_fsm_send_nibble_msb16(uint16_t b, uint8_t nibble) {
  usart_send(USART1, hexstr[(b >> (4*(3-nibble))) & 0x0f]);
}
static void usart_fsm_send_nibble_msb64(uint64_t b, uint8_t nibble) {
  usart_send(USART1, hexstr[(b >> (4*(15-nibble))) & 0x0f]);
}

// NOTE: will stop running if it doesn't transmit a character per call
// can be resumed by calling this function from outside the ISR
static void run_tx_fsm() {
  if (usart_get_flag(USART1, USART_ISR_TXE)) {
    switch (usart_state) {
    case USART_FSM_SAMPLES:
      if (usart_data.samples.word < SAMPLE_BUFFER_SZ) {
        if (usart_data.samples.nibble == 0) {
          usart_send(USART1, '0');
        } else if (usart_data.samples.nibble == 1) {
          usart_send(USART1, 'x');
        } else if (usart_data.samples.nibble < 6) {
          usart_fsm_send_nibble_msb16(samples[usart_data.samples.word], usart_data.samples.nibble-2);
        } else {
          usart_send(USART1, ',');
        }
      } else {
        if (usart_data.samples.nibble == 0) {
          usart_send(USART1, '\r');
        } else if (usart_data.samples.nibble == 1) {
          usart_send(USART1, '\n');
          sample_full = 0;
          usart_state = USART_FSM_IDLE;
        }
      }

      ++usart_data.samples.nibble;
      if (usart_data.samples.nibble > 6) {
        usart_data.samples.nibble = 0;
        ++usart_data.samples.word;
      }
      break;
    case USART_FSM_DEBUG:
      usart_state = USART_FSM_IDLE;
      break;
    case USART_FSM_WRITE_IQ_INIT:
      usart_data.iq.nibble = 0;
      usart_data.iq.word = 0;

      usart_state = USART_FSM_WRITE_IQ_DOWRITE;
      break;
    case USART_FSM_WRITE_IQ_DOWRITE:
      switch (usart_data.iq.word) {
      case 0:
        usart_fsm_send_nibble_msb64(usart_i, usart_data.iq.nibble);
        ++usart_data.iq.nibble;
        if (usart_data.iq.nibble == 16) {
          usart_data.iq.nibble = 0;
          ++usart_data.iq.word;
        }
        break;
      case 1:
        usart_send(USART1, '\r');
        ++usart_data.iq.word;
        break;
      case 2:
        usart_send(USART1, '\n');
        usart_state = USART_FSM_IDLE;
        iq_ready = 0;
        break;
      }
      break;
    case USART_FSM_IDLE:
    default:
      break;
    }
  }
  if (usart_state != USART_FSM_IDLE) {
    usart_enable_tx_interrupt(USART1);
  } else {
    usart_disable_tx_interrupt(USART1);
  }
}

// hp, 100 window
static int32_t feed_fir1(uint16_t i) {
  static uint16_t buf[FIR_HP_BUFFER_SZ] = {0};
  static uint8_t half_ptr = FIR_HP_BUFFER_SZ/2;
  static uint8_t cur_ptr = 0;
  static int32_t sum = 0;

  sum += i;
  sum -= buf[cur_ptr];
  buf[cur_ptr] = i;

  ++cur_ptr;
  if (cur_ptr >= FIR_HP_BUFFER_SZ) {
    cur_ptr = 0;
  }
  ++half_ptr;
  if (half_ptr >= FIR_HP_BUFFER_SZ) {
    half_ptr = 0;
  }
  
  return FIR_HP_BUFFER_SZ*buf[half_ptr] - sum;
}

// lp, 64 window
static int32_t feed_fir2(int32_t i) {
  static int32_t buf[FIR_LP_BUFFER_SZ1] = {0};
  static uint8_t cur_ptr = 0;
  static int32_t sum = 0;

  sum += i;
  sum -= buf[cur_ptr];
  buf[cur_ptr] = i;

  ++cur_ptr;
  if (cur_ptr >= FIR_LP_BUFFER_SZ1) {
    cur_ptr = 0;
  }
  
  return sum;
}

// lp, 32 window
static int32_t feed_fir3(int32_t i) {
  static int32_t buf[FIR_LP_BUFFER_SZ2] = {0};
  static uint8_t cur_ptr = 0;
  static int32_t sum = 0;

  sum += i;
  sum -= buf[cur_ptr];
  buf[cur_ptr] = i;

  ++cur_ptr;
  if (cur_ptr >= FIR_LP_BUFFER_SZ2) {
    cur_ptr = 0;
  }
  
  return sum;
}

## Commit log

2018-04-04 Reorganize slightly
    [pos-sensor.kicad_pcb, pos-sensor.sch]
2018-04-04 Improve rx multithreaded case by caching path calculations
2018-04-20 Finish most of schematic and start work on antenna designs; specified dimensions for receiving antenna appear to be unmanufacturable
    [stm32f070.csv]
2018-04-21 Start work on capactive sensor
    [capacitive.kicad_pcb, capacitive.sch]
2018-05-15 Start work on schematic
    [stm32f070.csv]
2018-05-18 Tweak simulations a bit TODO switch to Python
2018-05-18 Test new filter
2018-05-19 Schematic capture basically finished; TODO source and fp all components
    [capacitive.sch]
2018-05-19 Remove linear regulator and replace with resistor
    [capacitive.sch]
2018-05-19 Write script to autofill components; save before test
    [capacitive.sch]
2018-05-19 Autofill works!
    [capacitive.sch]
2018-05-19 Output list of components with missing footprints
2018-05-19 Add some footprints
    [capacitive.sch]
2018-05-20 Generate TI SOIC-8 footprint
    [capacitive.sch]
2018-05-20 Everything footprinted except for the scale coupling pads
    [capacitive.sch]
2018-05-20 Autofill components
    [capacitive.sch]
2018-05-20 Start work on caliper scale generation
    [capacitive.sch]
2018-05-20 Ignore pycache and correct for gap between scale bases in capacitance calculation
2018-05-20 Add scales to generator script
    [capacitive.kicad_pcb]
2018-05-21 Add generation for holes
    [capacitive.sch]
2018-05-22 Generate first revision Gerber files
    [capacitive-B.Cu.gbr, capacitive-B.Mask.gbr, capacitive-B.SilkS.gbr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]
2018-05-23 Add input capacitor to help set the input roll-off frequency; it seems to reduce ripple a fair amount
    [capacitive-B.Cu.gbr, capacitive-B.Mask.gbr, capacitive-B.SilkS.gbr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]
2018-05-24 Regenerate schematic PDF
2018-05-24 Extend board 2mm to improve mechanical strength of left drill holes and improve ground stitching under MCU
    [capacitive-B.Cu.gbr, capacitive-B.Mask.gbr, capacitive-B.SilkS.gbr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]
2018-05-24 Generate sensor scale
    [capacitive-B.Cu.gbr, capacitive-B.Mask.gbr, capacitive-B.SilkS.gbr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]
2018-06-23 Write zip generating files
    [capacitive-B.Cu.gbr, capacitive-B.Mask.gbr, capacitive-B.SilkS.gbr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]
2018-06-23 Generate BOM
    [capacitive-bom.csv, capacitive-mouser.csv, capacitive.sch]
2018-07-01 Fix mouser BOM generation, add in notes from current testing
    [capacitive-mouser.csv, capacitive.sch]
2018-07-13 Add OpenOCD config
    [capacitive.cfg]
2018-07-14 First attempt at building
    [capacitive.cfg]
2018-07-14 Add in some spots to experiment with filtering in the future
    [capacitive.sch]
2018-07-14 Update schematic a bit
    [capacitive.sch]
2018-07-14 Test UART; works!
2018-07-14 Working ADC data collection example
2018-07-14 Experiment with FIR parameters; current best is 128 tap high pass followed by a 64 tap low pass
2018-07-15 Synchronize ADC timing with the pulses
2018-07-15 Switch USART to nonblocking FSM
2018-07-15 Mark new best filter (it's been the best for a while, just forgot to fix the comment
2018-07-15 Move ADC processing into main loop
2018-07-15 Test filter cascade reordering; performance not affect, as expected
2018-07-15 Working C filter; type demotion is annoying
2018-07-15 Add FIR filter, start work on adding phase calculation
2018-07-16 Well it's not overflowing right now; save point in case I want to continue trying to do all the calculations offline; TODO explore ADC duty cycling; collect for five cycles while processing over ten 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
2018-07-16 Accuracy is about 0.03 mm; need to get rid of more of the noise
    [main.c]
2018-07-16 Print out position data on USART TODO verify measurement accuracy
2018-07-19 Add second stage of filtering
    [capacitive.sch]
2018-07-20 Save before autofill
    [capacitive.sch]
2018-07-20 Autofill first time
    [capacitive.sch]
2018-07-20 All parts sourced and netlist generated
    [capacitive.sch]
2018-07-21 Change scale size and finish relayout
    [capacitive-B.Cu.gbr, capacitive-B.Mask.gbr, capacitive-B.SilkS.gbr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]
2018-07-21 Relayout capacitive scale and regenerate all Gerber files
    [scale.kicad_pcb]
2018-07-21 Regenerate Mouser BOM and fix Mouser BOM gen bug
    [capacitive-bom.csv, capacitive-mouser.csv]
2018-07-21 Swap out MOSFET to RU1C001ZP
    [capacitive-bom.csv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]
2018-07-21 Add updated BOM
    [capacitive-mouser.csv]
2018-07-21 Fix reverse voltage MOSFET probably
    [capacitive-B.Cu.gbr, capacitive-B.Mask.gbr, capacitive-B.SilkS.gbr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]
2018-07-24 Regenerate Gerbers (didn't actually need to)
    [capacitive-B.Cu.gbr, capacitive-B.Mask.gbr, capacitive-B.SilkS.gbr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]
2018-07-24 Remove stuff from old Gerber files and fix zipfiles
    [capacitive-B.Cu.gbr, capacitive-B.Mask.gbr, capacitive-B.SilkS.gbr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]
2018-08-03 Convert over to Kicad 5, fix mistakes for next revision
    [capacitive-2018-08-01-07-55-28.sch, capacitive-bom.csv, capacitive-mouser.csv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]
2018-08-03 Regenerate all output files and update README
    [capacitive-B.Cu.gbr, capacitive-B.Mask.gbr, capacitive-B.SilkS.gbr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]
2018-08-03 Move capacitor so it doesn't cover some designators
    [capacitive-B.Cu.gbr, capacitive-B.Mask.gbr, capacitive-B.SilkS.gbr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]
2018-08-04 Flip offset pot around to make it more accessible TODO maybe remove offset pot to save cost
    [capacitive-B.Cu.gbr, capacitive-B.Mask.gbr, capacitive-B.SilkS.gbr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]
2019-06-30 Explore IIR filters; it seems like FIR windowing will have to do
